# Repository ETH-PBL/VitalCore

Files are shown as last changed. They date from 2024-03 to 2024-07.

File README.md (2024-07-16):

# VitalCore
Philipp Schilk, ETHZ D-ITET PBL
2022-2024

A Self-contained, Miniaturized, BLE-enabled Embedded Platform for Low-Power, Wearable, and Hearable Applications.

<p float="center" align="center">
  
  
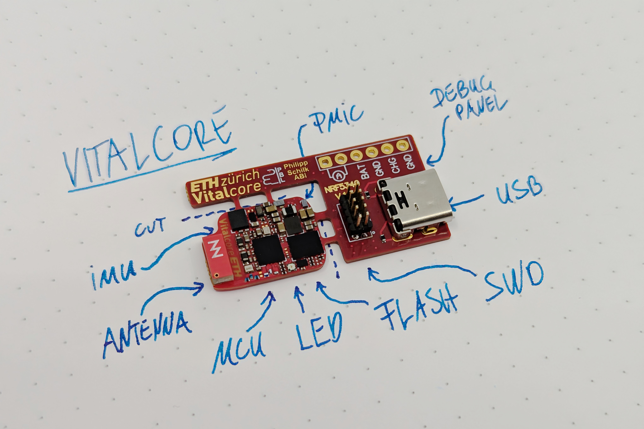
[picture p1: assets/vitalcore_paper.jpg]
  
  
</p>

Pictures: Frank K. Gürkaynak, 2022

## Quick Links

 - 📄 [Full Documentation](./hardware/VC_NRF5340/Documentation/Complete_1.3/VC_NRF5340_FULL_DOC.PDF)
 - 🌍 [Interactive HTML BOM](./hardware/VC_NRF5340/Documentation/Complete_1.3/VC_NRF5340-Complete.html)
 - 📦 [Gerbers](./hardware/VC_NRF5340/Documentation/Complete_1.3/Manufacturing)
 - 📦 [PnP Files](./hardware/VC_NRF5340/Documentation/Complete_1.3/PickAndPlace)
 - ⚙️  [Altium Project](./hardware/VC_NRF5340/)

## Changelog
 - 03/04/2024: First public release (Hardware v1.3)

## Overview

### VitalCore:

The VitalCore is a highly integrated, miniaturized embedded systems platform that features everything
a low-power wearable project usually requires - except for application specific sensors
and transducers. Its small 17.6 mm ** 12.6 mm size allows it to be integrated even in the most constraint
applications, include in-ear/hearable projects. Based around an NRF5340 SoC, the VitalCore features
a dual-core Cortex-M33 processor running at up to 128 MHz, 1 MB of Flash, 512 KB RAM, and BLE 5.2
complete with an on-board chip antenna.

### VitalPack Interface & Connectors:

On its back, the VitalCore features a 0.4 mm pitch 50-position connector that can be used to attach
application-specific 'VitalPack' expansion boards. This connector exposes power inputs and outputs,
the SoC's programming interface and USB port, and 28 GPIO pins with ADC, I2C, SPI, I2S, UART, QSPI, and PDM
interfaces available. The SWD pin, battery and charger connections, and QVAR inputs are also available as SMD solder
pads on the back side.

The exact pinout is specified in the [full documentation pdf](./hardware/VC_NRF5340/Documentation/Complete_1.3/VC_NRF5340_FULL_DOC.PDF).

To accommodate different stacking heights, the following combinations of header (on the VitalCore) and receptacles (on
the VitalPack) can be used:

| **Stacking Height** | **Header** | **Receptacle** |
| --- | --- | --- |
| 0.7mm | JAE Electronics WP7B-P050VA1-R8000 | JAE Electronics WP7B-S050VA1-R8000 |
| 1.5mm | Hirose DF40C-50DP-0.4V(51) | Hirose DF40C-50DS-0.4V(51) |
| 2.0mm | Hirose DF40C-2.0-50DP-0.4V(51) | Hirose DF40C-2.0-50DS-0.4V(51) |
| 2.5mm | Hirose DF40C-2.5-50DP-0.4V(51) | Hirose DF40C-2.5-50DS-0.4V(51) |

### Power:

A MAX77654 PMIC provides a full power subsystem, including a software-controlled battery charger with power path
switching and up to 300 mA charge current, a battery monitor, 3 software-controllable switch mode buck-boost converters each
with an output range of 0.8 V to 5.5 V, and two software-controlled LDOs each with an output range of 1.71 V to 5.3 V. All
on-board devices (SoC and peripherals) are powered using a dedicated 1.8 V buck converter, making all SMPS and LDO
outputs available application-specific circuitry via the VitalPack connector.

Power Diagram

### Peripherals:

The VitalCore comes equipped with the following peripherals:

 - A high-performance LSM6DSV16BX IMU with accelerometer, gyroscope and QVAR frontend.
 - A 256Mb W25Q256JWYIM QSPI Flash.
 - An RGB LED and IS31FL3194 driver capable of LED animations/patterns.

### Panel:

The VitalCore Altium project/gerber files include a panel to be used during development.
It exposes the NRF's SWD programming interface, USB port, power inputs, and power rail test points. It
can be removed manually by cutting the small PCB bridges, or be excluded before production entirely.

## Hardware

> [!IMPORTANT]
> Device sheet folder must be configured correctly in Altium for project to be opened correctly.

This project uses device sheets to for common building blocks (in `VC_Common`) that
are used in other projects. The folder `VC_Common/DevSheets` must be added to Altium's
list of device sheet locations! See below:

https://www.altium.com/documentation/altium-designer/device-sheets

To avoid annotation collision between components in device sheets and components within each project,
all device sheet components are annotated with a 'D' Suffix.  Altium should be able to handle this via
'Board Level Annotation', but it has been rather buggy.

Any modifications to device sheets don't seem to propagate to projects using those sheets until those
projects are closed & re-opened, or Altium is restarted.

## Firmware Template

**Will follow shortly**

## VitalPack Template

**Will follow shortly**

## Gallery & Examples

Examples of VitalCore-based projects:

### [TinyssimoRadar](https://github.com/ETH-PBL/TinyssimoRadar):
In-Ear Hand Gesture Recognition with Ultra-Low Power mmWave Radars.

<p align="center">
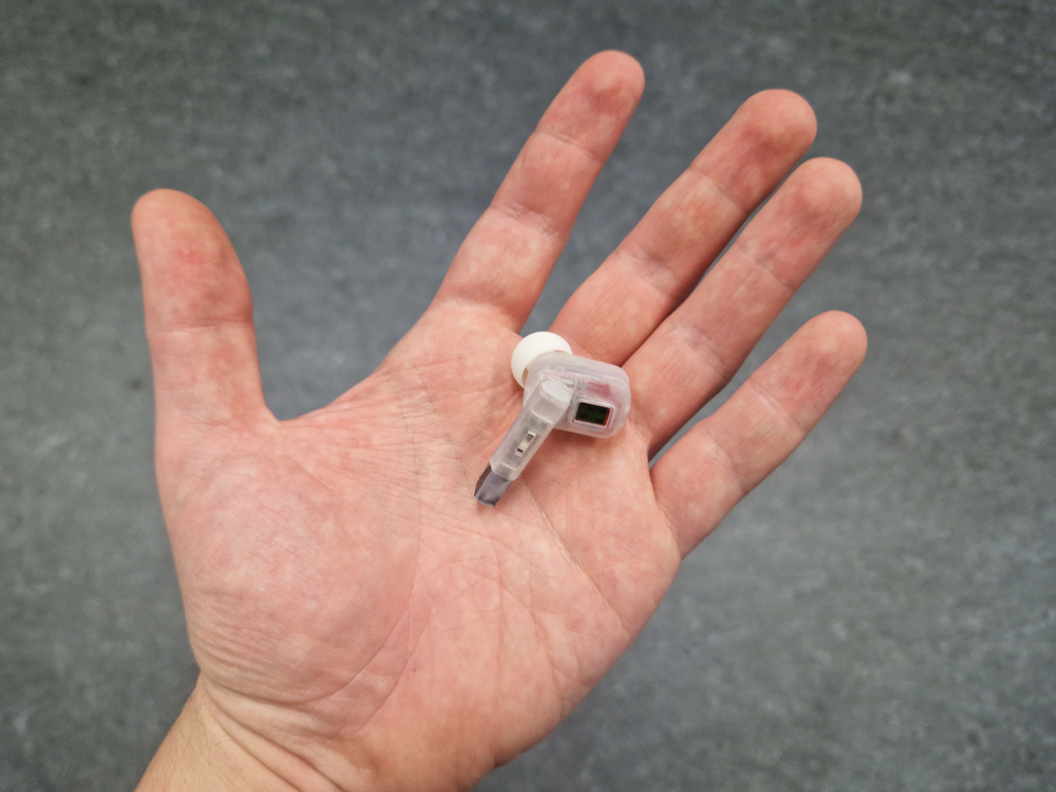
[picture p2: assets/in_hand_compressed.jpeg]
  
</p>

TinyssimoRadar Render

### VitalPod:
[*A Low Power In-Ear Vital Parameter Monitoring System*](https://ieeexplore.ieee.org/abstract/document/9941646)

### In-Ear-Voice:
[*Towards Milli-Watt Audio Enhancement With Bone-Conduction Microphones for In-Ear Sensing Platforms*](https://dl.acm.org/doi/abs/10.1145/3576842.3582365)

## License and Attribution

Published under the GNU GPLv3 license.

If you find VitalCore useful, we would appreciate if you cite one of the following papers:

📚 [Andrea Ronco, Philipp Schilk, Michele Magno, "TinyssimoRadar: In-Ear Hand Gesture Recognition with Ultra-Low Power mmWave Radars", *IoTDI'24*, 2024.](https://ieeexplore.ieee.org/abstract/document/10562162)
```bibtex
@inproceedings{TinyssimoRadar,
  author={Ronco, Andrea and Schilk, Philipp and Magno, Michele},
  booktitle={2024 IEEE/ACM Ninth International Conference on Internet-of-Things Design and Implementation (IoTDI)}, 
  title={TinyssimoRadar: In-Ear Hand Gesture Recognition with Ultra-Low Power mmWave Radars}, 
  year={2024},
  volume={},
  number={},
  pages={192-202},
  doi={10.1109/IoTDI61053.2024.00021}
}
```

📚 [Philipp Schilk, Niccolò Polvani, Andrea Ronco, Milos Cernak, Michele Magno, "In-Ear-Voice: Towards Milli-Watt Audio Enhancement With Bone-Conduction Microphones for In-Ear Sensing Platforms", *IoTDI'23*, 2023.](https://dl.acm.org/doi/abs/10.1145/3576842.3582365#)

```bibtex
@inproceedings{InEarVoice,
  author = {Schilk, Philipp and Polvani, Niccol\`{o} and Ronco, Andrea and Cernak, Milos and Magno, Michele},
  booktitle = {Proceedings of the 8th ACM/IEEE Conference on Internet of Things Design and Implementation},
  title = {In-Ear-Voice: Towards Milli-Watt Audio Enhancement With Bone-Conduction Microphones for In-Ear Sensing Platforms},
  year = {2023},
  isbn = {9798400700378},
  publisher = {Association for Computing Machinery},
  address = {New York, NY, USA},
  url = {https://doi.org/10.1145/3576842.3582365},
  doi = {10.1145/3576842.3582365},
  pages = {1–12},
  numpages = {12},
  series = {IoTDI '23}
}
```

📚 [Philipp Schilk, Kanika Dheman, Michele Magno,"VitalPod: A Low Power In-Ear Vital Parameter Monitoring System", *WiMob'22*, 2022.](https://ieeexplore.ieee.org/abstract/document/9941646)
```bibtex
@inproceedings{VitalPod,
  author={Schilk, Philipp and Dheman, Kanika and Magno, Michele},
  booktitle={2022 18th International Conference on Wireless and Mobile Computing, Networking and Communications (WiMob)}, 
  title={VitalPod: A Low Power In-Ear Vital Parameter Monitoring System}, 
  year={2022},
  volume={},
  number={},
  pages={94-99},
  doi={10.1109/WiMob55322.2022.9941646}
}
```

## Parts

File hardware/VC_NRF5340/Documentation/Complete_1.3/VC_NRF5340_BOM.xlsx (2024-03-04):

Designator | LibRef | Comment | Description | Quantity | Footprint | Manufacturer | Manufacturer Part Number | Supplier 1 | Supplier Part Number 1
C5D, C7, C8, C10, C11, C15 | CAP_0201_1u_10V | 1µF | CAP CER 1UF 10V X6S | 6 | CAP_0201 | Murata | GRM033C81A105ME05D | Mouser | 81-GRM033C81A105ME5D
C9 | CAP_0201_2.2n_16V | 2.2nF | CAP CER 2.2NF 16V X7R 0201 | 1 | CAP_0201 | Murata | GRM033R71C222KA88D | Mouser | 81-GRM033R71C222KA8D
C7D | CAP_0201_3.3n_16V | 3.3nF | CAP CER 3.3NF 16V X7R 0201 | 1 | CAP_0201 | Murata | GRM033R71C332KA88D | Mouser | 81-GRM033R71C332KA88
C1, C2, C2D, C3, C4, C5, C6, C14, C14D, C15D, C16D | CAP_0201_100n_10V | 100 nF | CAP CER 0.1UF 10V X5R 0201 | 11 | CAP_0201 | Murata | GRM033Z71A104KE14D | Mouser | 81-GRM033Z71A104KE4D
C17D, C18D | CAP_0201_110p_50V | 110pF | CAP CER 110PF 50V C0G 0201 | 2 | CAP_0201 | Murata | GRM0335C1H111JA01D | Mouser | 81-GRM0335C1H111JA1D
C3D, C4D, C12, C12D, C13, C13D | CAP_0402_4.7u_16V | 4.7µF | CAP CER 4.7UF 16V X5R 0402 | 6 | CAP_0402 | Kyocera AVX | 0402YD475MAT2A | Mouser | 581-0402YD475MAT2A
C6D | CAP_0402_10u_10V | 10µF | CAP CER 10UF 10V X5R 0402 | 1 | CAP_0402 | Samsung | CL05A106MP5NUNC | Mouser | 187-CL05A106MP5NUNC
C1D | CAP_0402_22u_6V3 | 22µF | CAP CER 22UF 6.3V X5R 0402 | 1 | CAP_0402 | Kyocera AVX | CM05X5R226M06AH080 | Mouser | 346-CM05X5R226M6AH80
C8D, C9D, C10D, C11D | CAP_0603_22u_10V | 22µF | CAP CER 22UF 10V X7R 0603 | 4 | CAP_0603 | Murata | GRM187R61A226ME15D | Mouser | 81-GRM187R61A226ME5D
C16 | CAP_RF_0201_0.7pF | 0.7pF | CAP RF CER 0.7PF 25V C0G 0201 | 1 | CAP_0201 | Murata | GJM0335C1ER70BB01D | Mouser | 81-GJM0335C1ER70BB1D
J2D | CONN_50P_M_COMBI_INTERFACE | Interface | 50Pin 0.4mm pitch connector footprint that accepts (male) connectors intended for different stacking heights: Hirose - DF40C-50DP-0.4V(51) for 1.5mm - 3mm stacking height JAE - WP7B-P050VA1-R8000 - for 0.7mm stacking height | 1 | CONN_COMBI_50P
J5D | CONN_PINHEADER_6PIN | 6Pin | 6 Pin Pinheader. | 1 | CONN_PINHEADER_6PIN
J4D | CONN_SWD | ARM SWD 10-pin | ARM 10-pin SWD Connector. | 1 | CONN_SWD |  |  | Mouser | 710-62201021121
J7D | CONN_USB_C | 213716-0001 USB-C | Connector USB Type C Receptacle 16 Position 0.5mm Surface Mount Right Angle Emboss T/R | 1 | CONN_USBC_2137160001 | Molex | 213716-0001 | Mouser | 538-213716-0001
D1D | D_NSR20F30NXT5G | NSR20F30NXT5G | Small Signal Schottky Diode, 30 V, 2 A | 1 | DSN2_ONSemi | ON Semiconductor | NSR20F30NXT5G | Mouser | 863-NSR20F30NXT5G
D2D | D_RGB_LED | SML-LX0404SIUPGUSB | SML-LX0404SIUPGUSB RGB LED | 1 | SML-LX0404SIUPGUSB | Lumex | SML-LX0404SIUPGUSB | Mouser | 696-LX0404SIUPGUSB
U7D | IS31FL3194 | IS31FL3194 | LED Driver with Programmable Pattern Sequencing 3-Channel 40mA 8-Pin WCSP T/R | 1 | WLCSP_8_P0.4 | ISSI | IS31FL3194-CLS2-TR | Digi-Key | 2521-IS31FL3194-CLS2-TRCT-ND
JP1D | JMP_0201 | 0R | ERJ Series 0201 0 Ohm 0.05 W Jumper Surface Mount Thick Film Chip Resistor | 1 | JMP_0201 | Panasonic | ERJ-1GN0R00C | Mouser | 667-ERJ-1GN0R00C
J1, J2, J3, J4, J5 | JMP_0201_3WAY | Solder Jumper | Solder Jumper 3 Pads | 5 | JMP_0201_3WAY | Panasonic | ERJ-1GN0R00C | Mouser | 667-ERJ-1GN0R00C
L1D | L_0603_2.2uH_520mA | 2.2µH | L 2.2uH 520mA 0603 | 1 | IND_0603 | Taiyo Yuden | MBKK1608T2R2M | Mouser | 963-MBKK1608T2R2M
L1, L2 | L_0603_10uH_300mA | 10µH | L 10uH 300mA 0603 | 2 | IND_0603 | Murata | LQM18DN100M70L | Mouser | 81-LQM18DN100M70L
L2D | L_0805_1.5uH_2A | 1.5µH | L 1.5uH 2A 0805 | 1 | IND_0805_DFE201210S | Murata | DFE201210S-1R5M=P2 | Mouser | 81-DFE201210S-1R5MP2
L4, L5 | L_RF_0201_2.2nH | 2.2nH | L 2.2nH RF 0201 | 2 | IND_0201_MURATA_LQW03AW | Murata | LQP03HQ2N2B02D | Mouser | 81-LQP03HQ2N2B02D
L3, L6, L7 | L_RF_0201_5.6nH | 5.6nH | L 5.6nH RF 0201 | 3 | IND_0201_MURATA_LQW03AW | Murata | LQW03AW5N6J00D | Mouser | 81-LQW03AW5N6J00D
U6D | LSM6DSV16BX | LSM6DSV16BX | IMU ACCEL/GYRO I2C/SPI 14LGA | 1 | LGA-14_STM | STMicroelectronics | LSM6DSV16BX | Mouser | 511-LSM6DSV16BXTR
U1D | MAX38640BENT18+T | MAX38640BENT18+T | Buck Switching Regulator IC Positive Fixed 1.8V 1 Output 175mA 6-WLP | 1 | THIN_WLP_6_MAX38640 | Maxim | MAX38640BENT18+T | Mouser | 700-MAX38640BENT18T
U2D | MAX77654BENV+T | MAX77654BENV+T | Buck-Boost Converter With LDO Regulator 5-OUT 30-Pin WLP T/R | 1 | WLP_30_MAX77654 | Maxim | MAX77654BENV+T | Mouser | 700-MAX77654BENV+T
E1 | NN03-320 | NN03-320 | Integrated Chip Antenna | 1 | NN03-320 | Fractus Antennas | NN03-320 | Mouser | 128-NN03-320
U1 | nRF5340-CLAA | nRF5340-CLAA | Multi-protocol Bluetooth Low Energy, IEEE 802.15.4, ANT and 2.4GHz proprietary system-on-chip | 1 | NRF5340_WLCSP | Nordic | NRF5340-CLAA-R7 | Mouser | 949-NRF5340-CLAA-R7
RT1D | NTC_0201_10k | 10kR | NTC 10K 1% 0201 3380K | 1 | RES_0201 | Panasonic | ERTJZEG103FA | Mouser | 667-ERT-JZEG103FA
U4D | PESD1USB30 | PESD1USB30 | ESD Suppressor Diode TVS Uni-Dir 5V 5-Pin WLCSP T/R | 1 | WLCSP_5_2-1-2_P0.4 | NXP Semiconductors | PESD1USB30 | Mouser | 771-PESD1USB30Z
R1, R2 | R_0201_2.2K | 2.2kR | R 2.2K 1% 50mW 0201 | 2 | RES_0201 | Panasonic | ERJ-1GNF2201C | Mouser | 667-ERJ-1GNF2201C
R3 | R_0201_2.2R | 2.2R | R 2.2R 1% 50mW 0201 | 1 | RES_0201 | Yageo | RC0201FR-072R2L | Mouser | 603-RC0201FR-072R2L
R4, R6D | R_0201_10K | 10kR | R 10K 1% 50mW 0201 | 2 | RES_0201 | Panasonic | ERJ-1GNF1002C | Mouser | 667-ERJ-1GNF1002C
R2D, R3D | R_0201_100K | 100kR | R 100K 1% 50mW 0201 | 2 | RES_0201 | Panasonic | ERJ-1GNF1003C | Mouser | 667-ERJ-1GNF1003C
R4D, R5D | R_0402_5K1 | 5K1 | R 5120R 1% 100mW 0402 | 2 | RES_0402 | Panasonic | ERJ-2RKF5101X | Mouser | 667-ERJ-2RKF5101X
U5D | W25Q256JWYIM | W25Q256JWYIM | NOR-Flash spiFlash, 1.8V, 256M-bit, 4Kb Uniform Sector, DTR | 1 | WLCSP_32_W25Q256JWYIM | Winbond | W25Q256JWYIM TR | Mouser | 454-W25Q256JWYIMTR
Y2 | Y_ECS-320-7-48B-JTM-TR5 | ECS-320-7-48B-JTM-TR5 (32MHz) | Crystal 32MHz 7pF ±20ppm ±20ppm 4-Pin Ultraminiature CSMD T/R | 1 | Y_ECX-1048 | ECS International | ECS-320-7-48B-JTM-TR5 | Mouser | 520-ECS320748BJTMTR5
Y1 | Y_ECS-327-9-1210 | ECS-.327-9-1210 (32.768kHz) | Crystal 32.768KHZ 9PFSMD ECX-1210 Khz Crystal 32.768KHZ 20PPM 90K Ohm -40C ~ 85C 2-SMD | 1 | Y_ECX-1210 | ECS International | ECS-.327-9-1210-TR | Mouser | 520-.327-9-1210T

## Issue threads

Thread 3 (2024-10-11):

Hardware: incorrect connection of W25Q256JW CS line

villanif, 2024-10-11:
W25Q256JW user manual specifies that "The /CS input must track the VCC supply level at power-up and power-down" (Page 10, section 4.1).

This issue can be solved by adding a pull-up resistor to the CS line

It is not sufficient to set the CS pin of the NRF53 pin to pull-up, as all pins are high-impedance during powerup

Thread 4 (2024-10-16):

Network Core Power Draw

schilkp, 2024-10-16:
Unexpected high DC power draw.

Tested with a VC with only the NRF53 soldered and powered directly via 1.8V.
With the network core enabled with BLE image and app core in sleep, power draw is around 5mA @ 1.8V
With the network core disabled and app core in sleep, power draw is less than 50uA @ 1.8V

Code to disable network core:
```c
NRF_RESET->NETWORK.FORCEOFF = RESET_NETWORK_FORCEOFF_FORCEOFF_Hold;
```

Seems like a hardware issue related to the network core? possibly oscillator or GPIO related?

villanif, 2024-10-16:
I briefly investigated if the issue could possibly be oscillator-related. In my opinion even with wrong oscillator parameters a 5mA draw cannot be explained, as a wrong oscillator setup should draw at most in the order of hundreds of uA (current can only be drawn by loading and unloading the capacitor). I guess the more likely explanation is a wrong GPIO configuration. According to the datasheet, GPIO electrical specifications, the current draw for the standard drive of the GPIO pin, the output set high, is at least 3 mA. If one grounded pin is pulled high by NRF, this would explain the data consumption.

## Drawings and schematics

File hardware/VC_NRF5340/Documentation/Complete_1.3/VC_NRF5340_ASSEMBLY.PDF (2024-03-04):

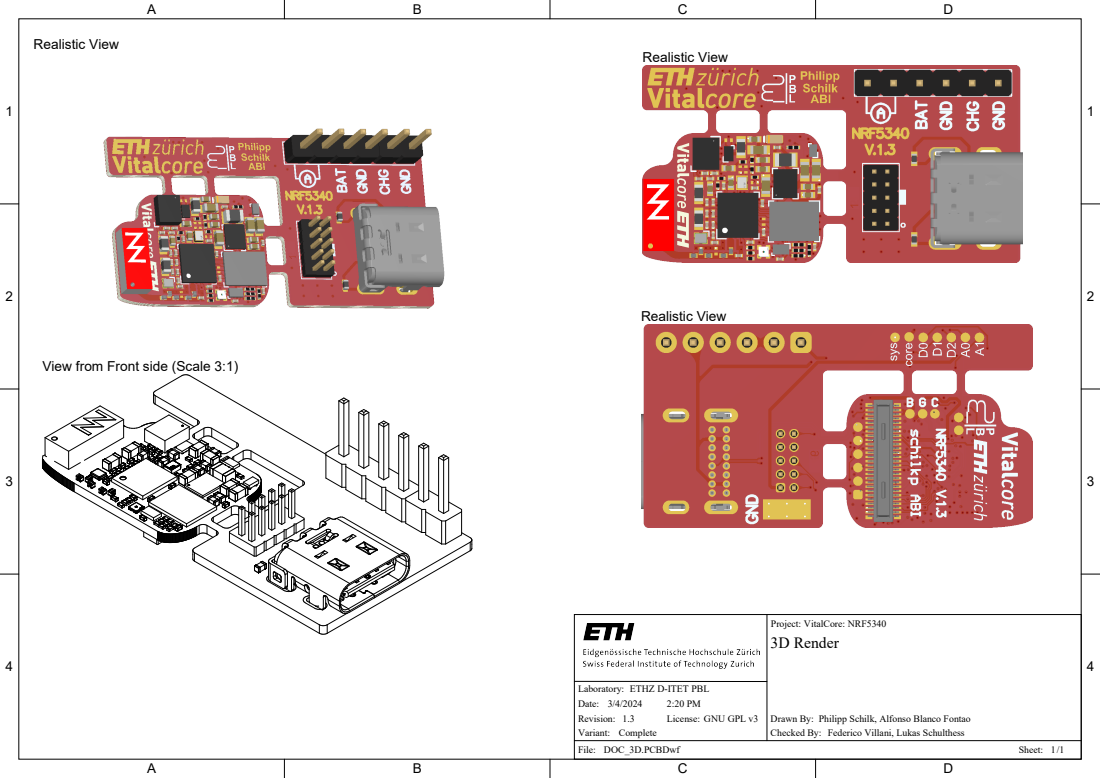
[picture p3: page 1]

View from Front side (Scale 3:1)

Drawn By: Philipp Schilk, Alfonso Blanco Fontao
Checked By:

Federico Villani, Lukas Schulthess

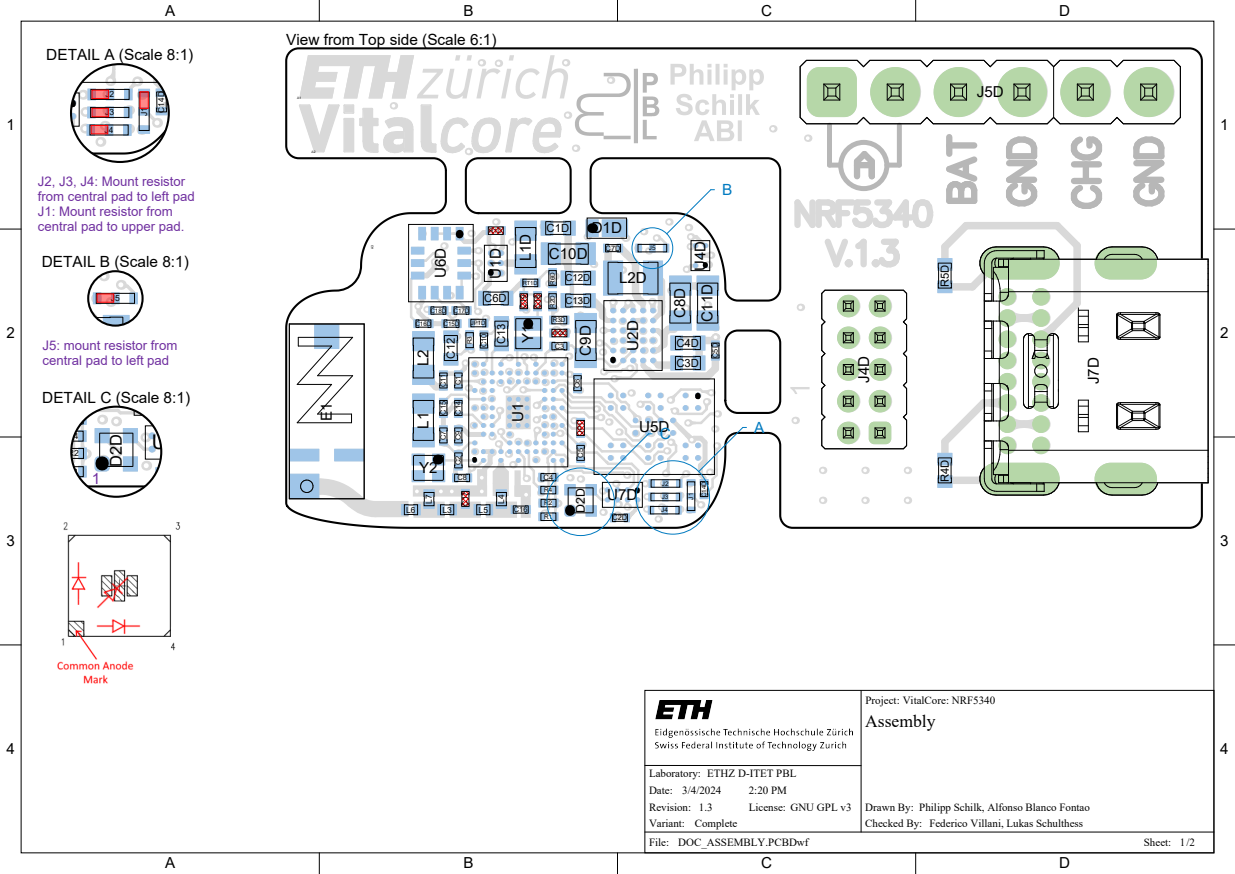
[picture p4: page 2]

View from Top side (Scale 6:1)

J2, J3, J4: Mount resistor
from central pad to left pad
J1: Mount resistor from
central pad to upper pad.

J5: mount resistor from
central pad to left pad
DETAIL C (Scale 8:1)

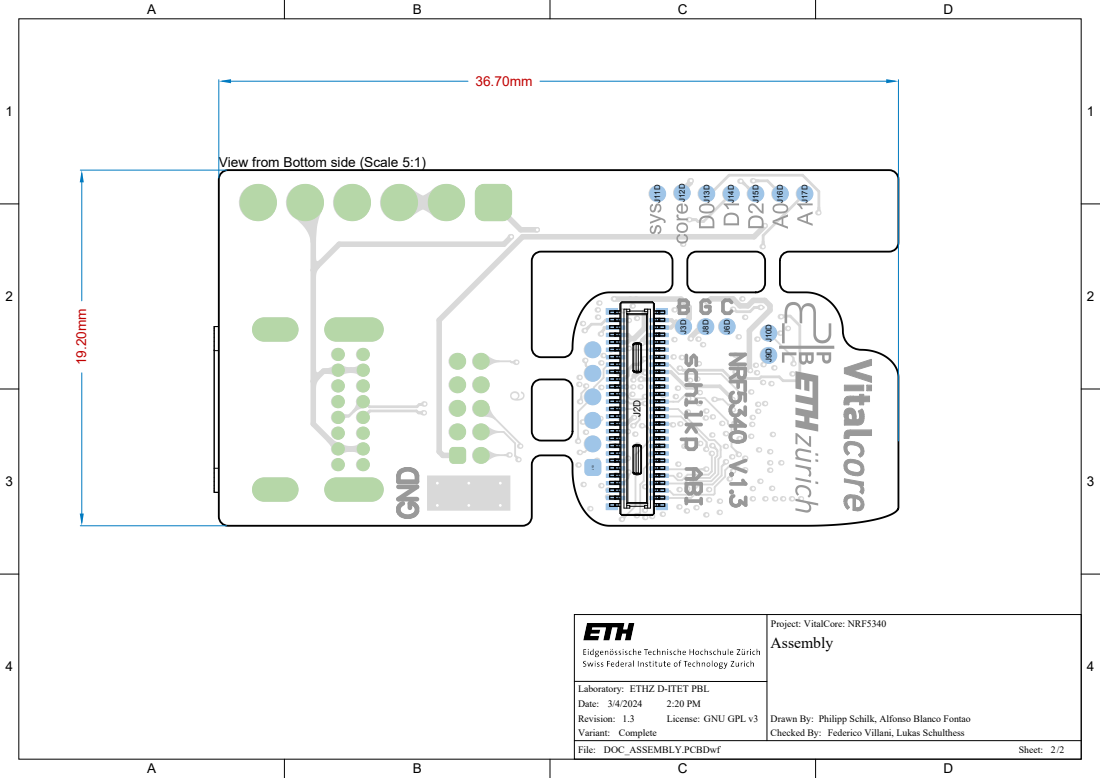
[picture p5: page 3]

View from Bottom side (Scale 5:1)

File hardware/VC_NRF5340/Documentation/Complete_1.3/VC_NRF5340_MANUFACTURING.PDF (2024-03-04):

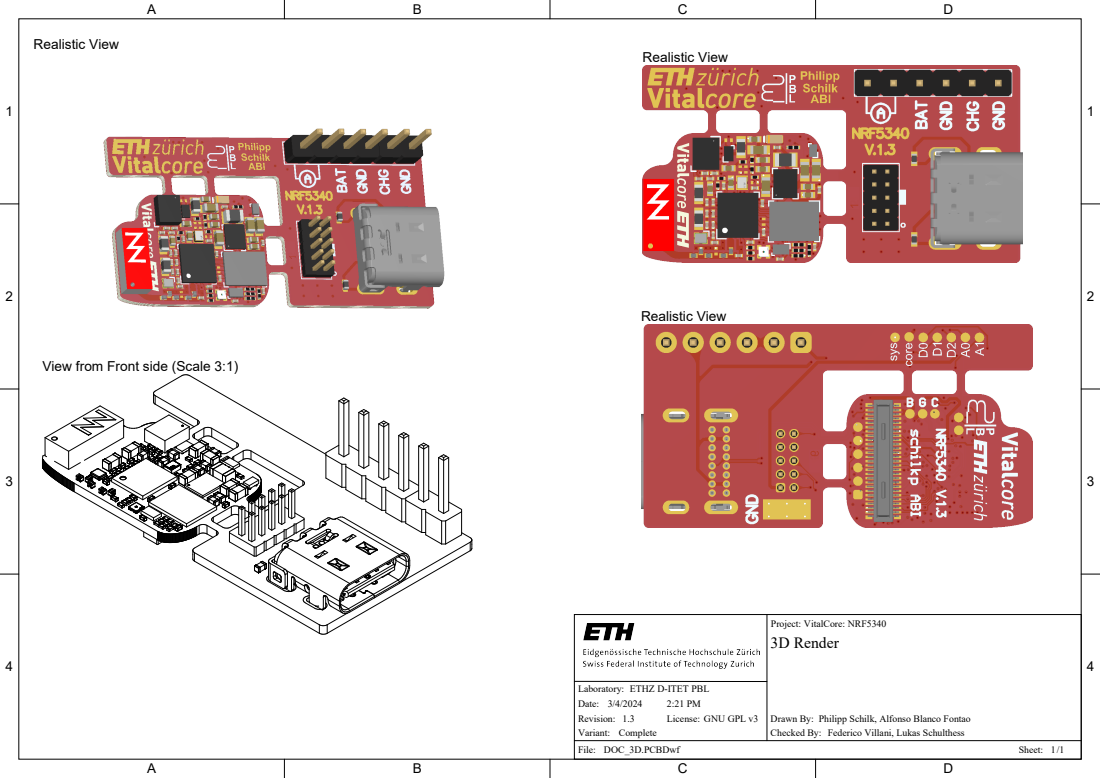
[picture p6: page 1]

View from Front side (Scale 3:1)

Drawn By: Philipp Schilk, Alfonso Blanco Fontao
Checked By:

Federico Villani, Lukas Schulthess

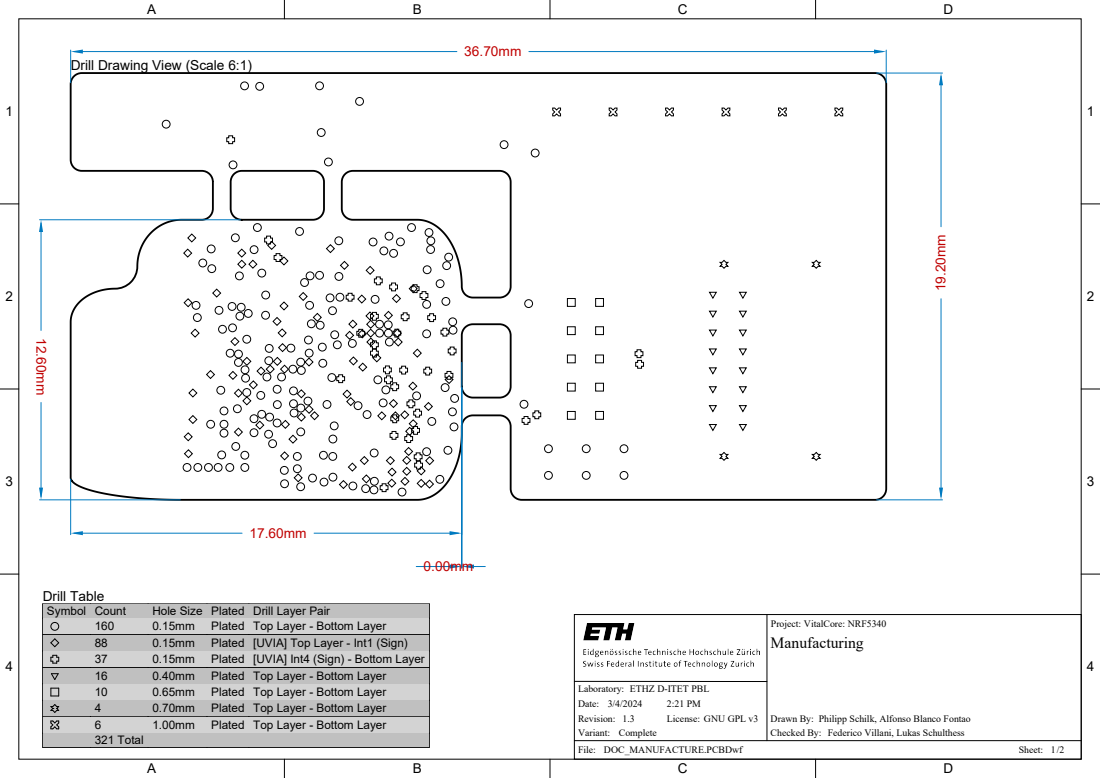
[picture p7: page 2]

Drill Drawing View (Scale 6:1)

Symbol | Count | Hole Size | Plated | Drill Layer Pair

160 | 0.15mm | Plated | Top Layer - Bottom Layer
88 | 0.15mm | Plated | [UVIA] Top Layer - Int1 (Sign)
37 | 0.15mm | Plated | [UVIA] Int4 (Sign) - Bottom Layer
16 | 0.40mm | Plated | Top Layer - Bottom Layer
10 | 0.65mm | Plated | Top Layer - Bottom Layer
4 | 0.70mm | Plated | Top Layer - Bottom Layer
6 | 1.00mm | Plated | Top Layer - Bottom Layer
321 Total

Project: VitalCore: NRF5340 Manufacturing

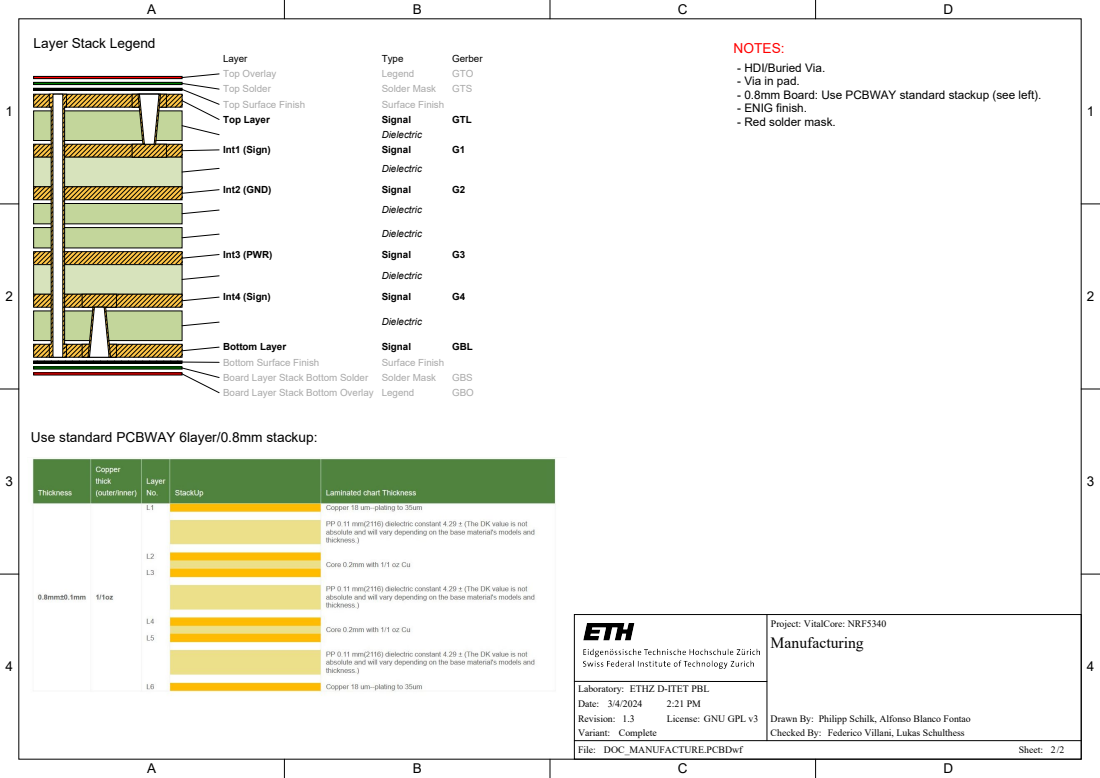
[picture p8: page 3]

NOTES:
- HDI/Buried Via.
- Via in pad.
- 0.8mm Board: Use PCBWAY standard stackup (see left).
- ENIG finish.
- Red solder mask.

Use standard PCBWAY 6layer/0.8mm stackup:

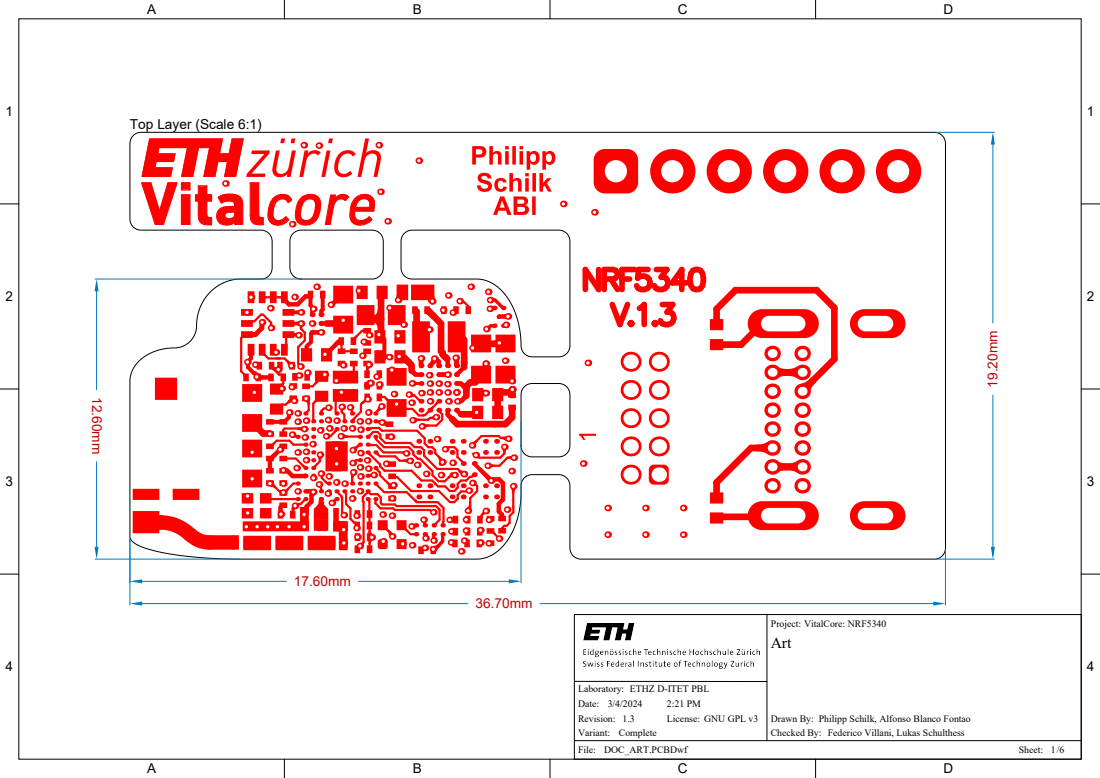
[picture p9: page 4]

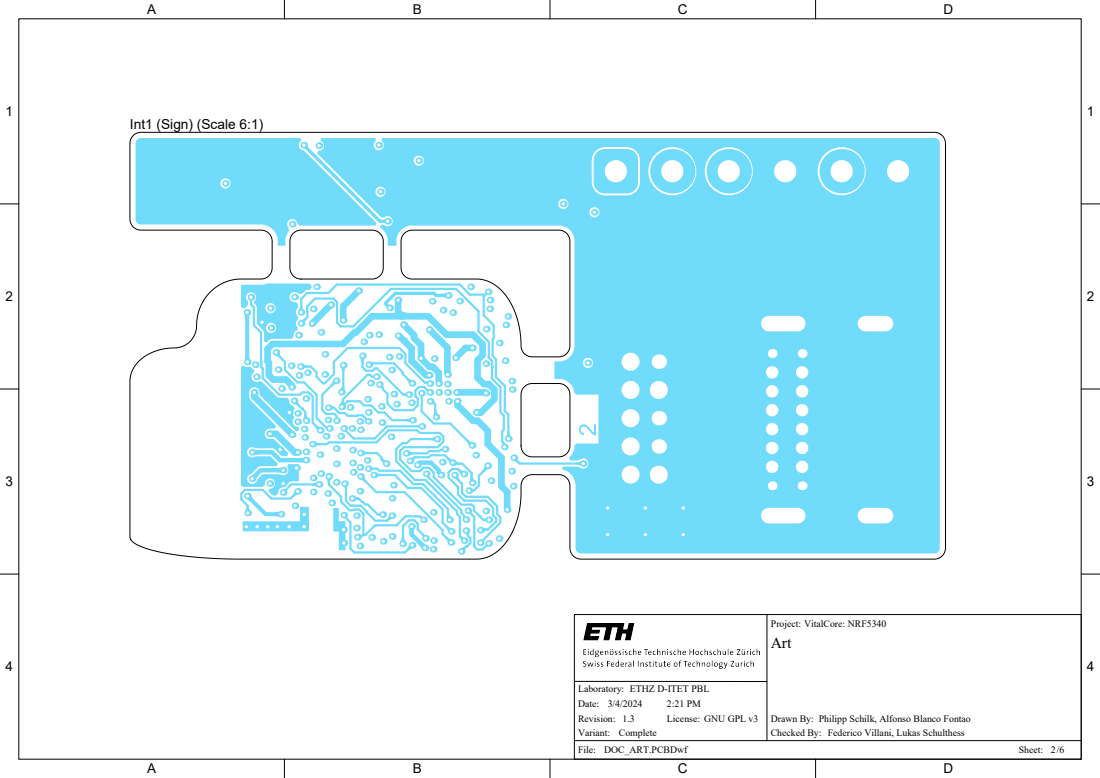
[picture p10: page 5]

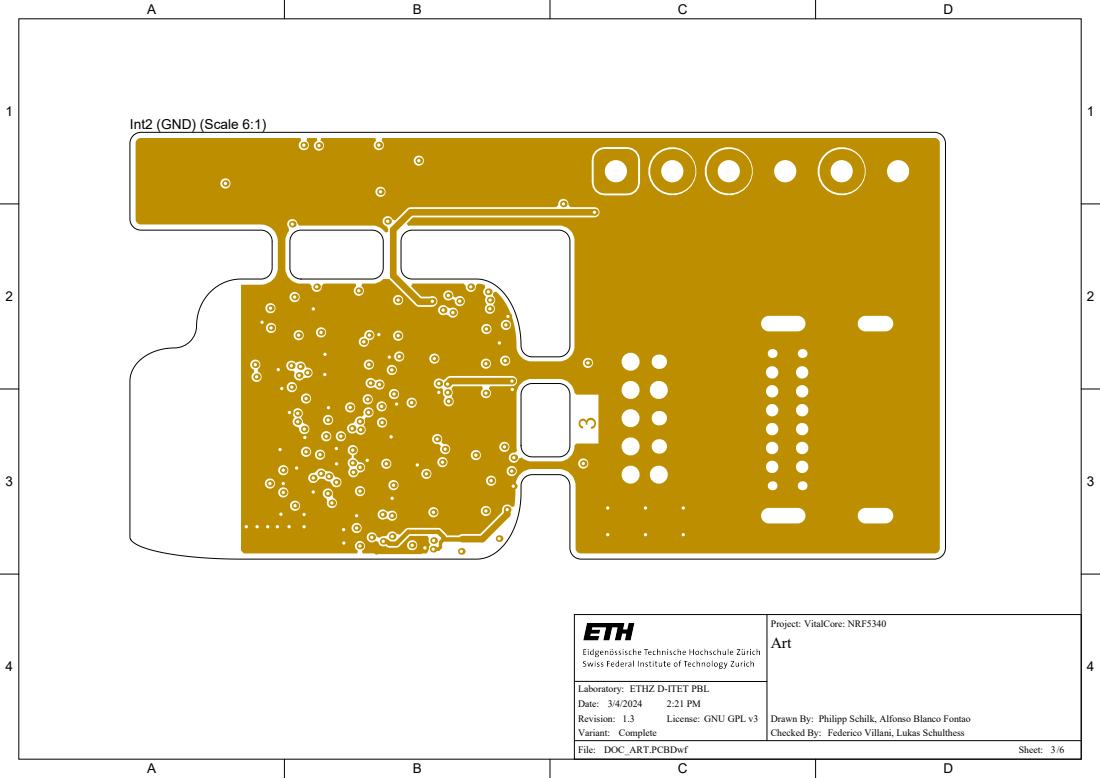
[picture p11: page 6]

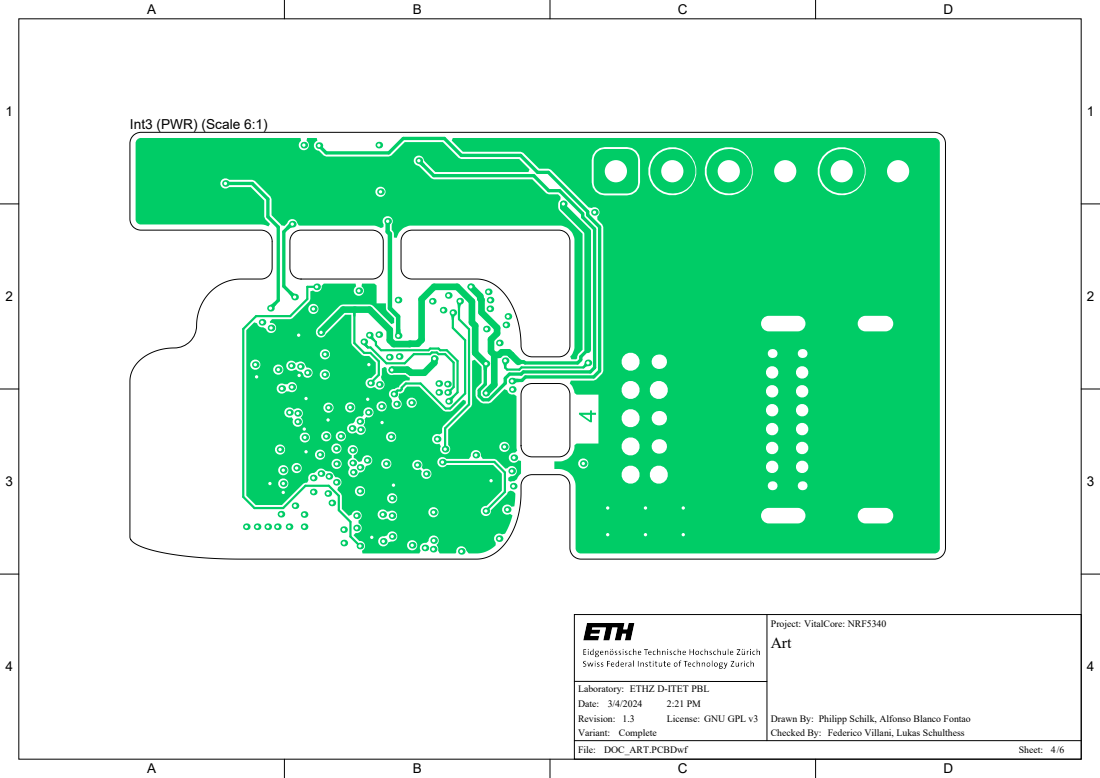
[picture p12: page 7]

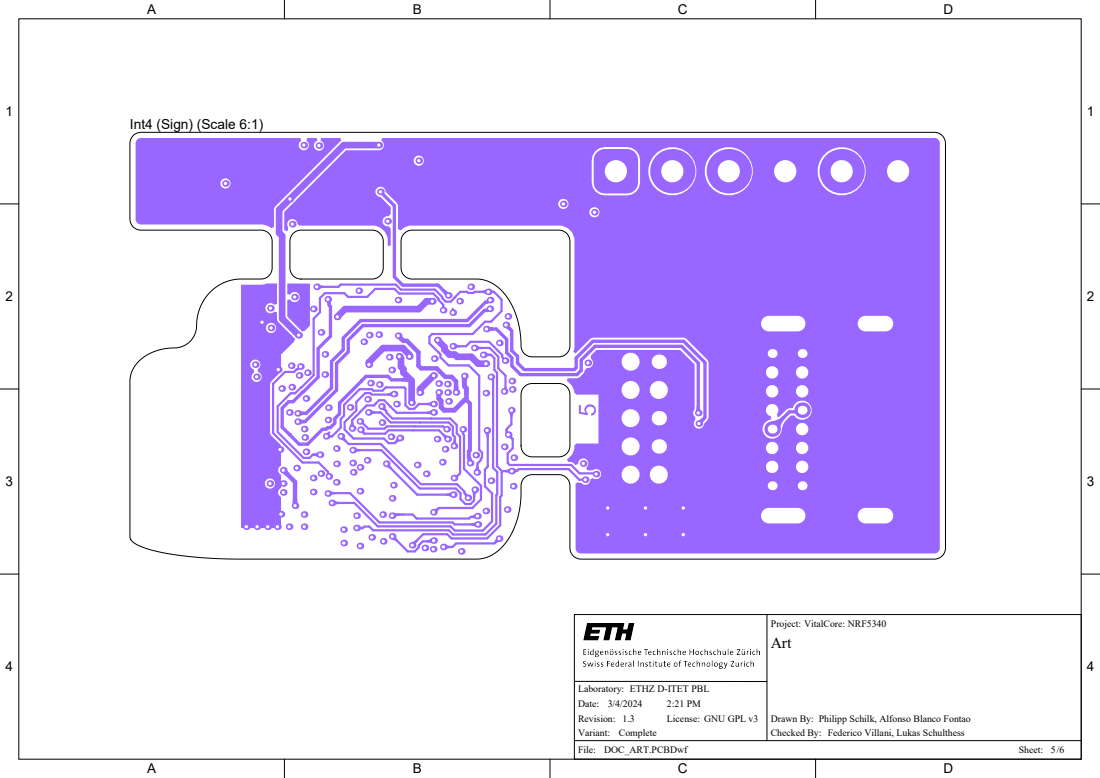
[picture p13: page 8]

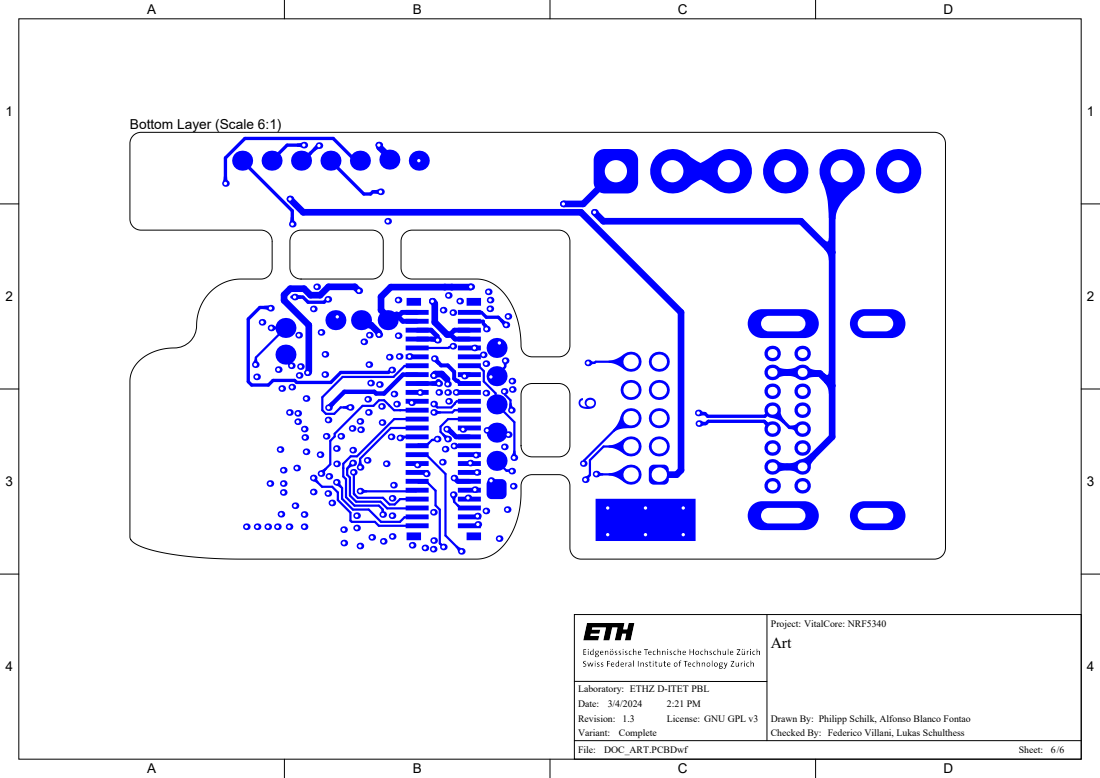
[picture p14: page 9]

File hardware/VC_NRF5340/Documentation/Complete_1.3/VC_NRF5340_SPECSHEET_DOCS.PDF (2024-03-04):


View from Front side (Scale 3:1)

Drawn By: Philipp Schilk, Alfonso Blanco Fontao
Checked By:

Federico Villani, Lukas Schulthess


View from Top side (Scale 6:1)

J2, J3, J4: Mount resistor
from central pad to left pad
J1: Mount resistor from
central pad to upper pad.

J5: mount resistor from
central pad to left pad
DETAIL C (Scale 8:1)


View from Bottom side (Scale 5:1)


View from Bottom side (Scale 2:1)


View from Top side (Scale 3:1)

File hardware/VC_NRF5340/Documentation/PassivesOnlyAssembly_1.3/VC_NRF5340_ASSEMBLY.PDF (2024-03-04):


View from Front side (Scale 3:1)

Drawn By: Philipp Schilk, Alfonso Blanco Fontao
Checked By:

Federico Villani, Lukas Schulthess


View from Top side (Scale 6:1)

J2, J3, J4: Mount resistor
from central pad to left pad
J1: Mount resistor from
central pad to upper pad.

J5: mount resistor from
central pad to left pad
DETAIL C (Scale 8:1)


View from Bottom side (Scale 5:1)

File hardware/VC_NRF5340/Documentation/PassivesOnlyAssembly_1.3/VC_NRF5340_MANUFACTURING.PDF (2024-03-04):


View from Front side (Scale 3:1)

Drawn By: Philipp Schilk, Alfonso Blanco Fontao
Checked By:

Federico Villani, Lukas Schulthess


Drill Drawing View (Scale 6:1)

Symbol | Count | Hole Size | Plated | Drill Layer Pair

160 | 0.15mm | Plated | Top Layer - Bottom Layer
88 | 0.15mm | Plated | [UVIA] Top Layer - Int1 (Sign)
37 | 0.15mm | Plated | [UVIA] Int4 (Sign) - Bottom Layer
16 | 0.40mm | Plated | Top Layer - Bottom Layer
10 | 0.65mm | Plated | Top Layer - Bottom Layer
4 | 0.70mm | Plated | Top Layer - Bottom Layer
6 | 1.00mm | Plated | Top Layer - Bottom Layer
321 Total

Project: VitalCore: NRF5340 Manufacturing


NOTES:
- HDI/Buried Via.
- Via in pad.
- 0.8mm Board: Use PCBWAY standard stackup (see left).
- ENIG finish.
- Red solder mask.

Use standard PCBWAY 6layer/0.8mm stackup:







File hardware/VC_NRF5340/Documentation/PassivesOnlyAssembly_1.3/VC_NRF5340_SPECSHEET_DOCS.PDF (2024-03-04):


View from Front side (Scale 3:1)

Drawn By: Philipp Schilk, Alfonso Blanco Fontao
Checked By:

Federico Villani, Lukas Schulthess


View from Top side (Scale 6:1)

J2, J3, J4: Mount resistor
from central pad to left pad
J1: Mount resistor from
central pad to upper pad.

J5: mount resistor from
central pad to left pad
DETAIL C (Scale 8:1)


View from Bottom side (Scale 5:1)


View from Bottom side (Scale 2:1)


View from Top side (Scale 3:1)

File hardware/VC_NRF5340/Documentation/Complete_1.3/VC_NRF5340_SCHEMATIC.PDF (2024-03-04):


VitalCore Logo VitalCore Vitalcore ETH Logo Vitalcore ETH


L 5
L 1 1


or may act as
nected



1 1


Drawn By:
Checked By: Federico Villani, Lukas Schulthess


Line # | Designator | Comment | Quantity | Design Item Id | Manufacturer | Manufacturer Part Number
1 | C1, C2, C2D, C3, C4, C5, C6, C14, C14D, C15D, C16D | 100 nF | 11 | CAP_0201_100n_10V | Murata | GRM033Z71A104KE14D

2 | C1D | 22µF | 1 | CAP_0402_22u_6V3 | Kyocera AVX | CM05X5R226M06AH080
3 | C3D, C4D, C12, C12D, C13, C13D | 4.7µF | 6 | CAP_0402_4.7u_16V | Kyocera AVX | 0402YD475MAT2A
4 | C5D, C7, C8, C10, C11, C15 | 1µF | 6 | CAP_0201_1u_10V | Murata | GRM033C81A105ME05D
5 | C6D | 10µF | 1 | CAP_0402_10u_10V | Samsung | CL05A106MP5NUNC
6 | C7D | 3.3nF | 1 | CAP_0201_3.3n_16V | Murata | GRM033R71C332KA88D
7 | C8D, C9D, C10D, C11D | 22µF | 4 | CAP_0603_22u_10V | Murata | GRM187R61A226ME15D
8 | C9 | 2.2nF | 1 | CAP_0201_2.2n_16V | Murata | GRM033R71C222KA88D
9 | C16 | 0.7pF | 1 | CAP_RF_0201_0.7pF | Murata | GJM0335C1ER70BB01D
10 | C17D, C18D | 110pF | 2 | CAP_0201_110p_50V | Murata | GRM0335C1H111JA01D
11 | D1D | NSR20F30NXT5G | 1 | D_NSR20F30NXT5G | ON Semiconductor | NSR20F30NXT5G
12 | D2D | SML-LX0404SIUPGUSB | 1 | D_RGB_LED | Lumex | SML-LX0404SIUPGUSB
13 | E1 | NN03-320 | 1 | NN03-320 | Fractus Antennas | NN03-320
14 | J1, J2, J3, J4, J5 | Solder Jumper | 5 | JMP_0201_3WAY | Panasonic | ERJ-1GN0R00C
15 | J2D | Interface | 1 | CONN_50P_M_COMBI_INT ERFACE

16 | J4D | ARM SWD 10-pin | 1 | CONN_SWD
17 | J5D | 6Pin | 1 | CONN_PINHEADER_6PIN
18 | J7D | 213716-0001 USB-C | 1 | CONN_USB_C | Molex | 213716-0001
19 | JP1D | 0R | 1 | JMP_0201 | Panasonic | ERJ-1GN0R00C
20 | L1, L2 | 10µH | 2 | L_0603_10uH_300mA | Murata | LQM18DN100M70L
21 | L1D | 2.2µH | 1 | L_0603_2.2uH_520mA | Taiyo Yuden | MBKK1608T2R2M
22 | L2D | 1.5µH | 1 | L_0805_1.5uH_2A | Murata | DFE201210S-1R5M=P2
23 | L3, L6, L7 | 5.6nH | 3 | L_RF_0201_5.6nH | Murata | LQW03AW5N6J00D
24 | L4, L5 | 2.2nH | 2 | L_RF_0201_2.2nH | Murata | LQP03HQ2N2B02D
25 | R1, R2 | 2.2kR | 2 | R_0201_2.2K | Panasonic | ERJ-1GNF2201C
26 | R2D, R3D | 100kR | 2 | R_0201_100K | Panasonic | ERJ-1GNF1003C
27 | R3 | 2.2R | 1 | R_0201_2.2R | Yageo | RC0201FR-072R2L
28 | R4, R6D | 10kR | 2 | R_0201_10K | Panasonic | ERJ-1GNF1002C
29 | R4D, R5D | 5K1 | 2 | R_0402_5K1 | Panasonic | ERJ-2RKF5101X
30 | RT1D | 10kR | 1 | NTC_0201_10k | Panasonic | ERTJZEG103FA
31 | U1 | nRF5340-CLAA | 1 | nRF5340-CLAA | Nordic | NRF5340-CLAA-R7
32 | U1D | MAX38640BENT18+T | 1 | MAX38640BENT18+T | Maxim | MAX38640BENT18+T
33 | U2D | MAX77654BENV+T | 1 | MAX77654BENV+T | Maxim | MAX77654BENV+T
34 | U4D | PESD1USB30 | 1 | PESD1USB30 | NXP Semiconductors | PESD1USB30
35 | U5D | W25Q256JWYIM | 1 | W25Q256JWYIM | Winbond | W25Q256JWYIM TR
36 | U6D | LSM6DSV16BX | 1 | LSM6DSV16BX | STMicroelectronics | LSM6DSV16BX
37 | U7D | IS31FL3194 | 1 | IS31FL3194 | ISSI | IS31FL3194-CLS2-TR
38 | Y1 | ECS-.327-9-1210 (32.768kHz) | 1 | Y_ECS-327-9-1210 | ECS International | ECS-.327-9-1210-TR
39 | Y2 | ECS-320-7-48B-JTM-TR5 (32MHz) | 1 | Y_ECS-320-7-48B-JTM-TR5 | ECS International | ECS-320-7-48B-JTM-TR5

Drawn By: Philipp Schilk, Alfonso Blanco Fontao
Checked By:

Federico Villani, Lukas Schulthess

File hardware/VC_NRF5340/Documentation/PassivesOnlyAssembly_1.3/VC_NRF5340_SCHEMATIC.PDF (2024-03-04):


VitalCore Logo VitalCore Vitalcore ETH Logo Vitalcore ETH


L 5
L 1 1


or may act as
nected



1 1


Drawn By:
Checked By: Federico Villani, Lukas Schulthess


Line # | Designator | Comment | Quantity | Design Item Id | Manufacturer | Manufacturer Part Number
1 | C1, C2, C2D, C3, C4, C5, C6, C14, C14D, C15D, C16D | 100 nF | 11 | CAP_0201_100n_10V | Murata | GRM033Z71A104KE14D

2 | C1D | 22µF | 1 | CAP_0402_22u_6V3 | Kyocera AVX | CM05X5R226M06AH080
3 | C3D, C4D, C12, C12D, C13, C13D | 4.7µF | 6 | CAP_0402_4.7u_16V | Kyocera AVX | 0402YD475MAT2A
4 | C5D, C7, C8, C10, C11, C15 | 1µF | 6 | CAP_0201_1u_10V | Murata | GRM033C81A105ME05D
5 | C6D | 10µF | 1 | CAP_0402_10u_10V | Samsung | CL05A106MP5NUNC
6 | C7D | 3.3nF | 1 | CAP_0201_3.3n_16V | Murata | GRM033R71C332KA88D
7 | C8D, C9D, C10D, C11D | 22µF | 4 | CAP_0603_22u_10V | Murata | GRM187R61A226ME15D
8 | C9 | 2.2nF | 1 | CAP_0201_2.2n_16V | Murata | GRM033R71C222KA88D
9 | C16 | 0.7pF | 1 | CAP_RF_0201_0.7pF | Murata | GJM0335C1ER70BB01D
10 | C17D, C18D | 110pF | 2 | CAP_0201_110p_50V | Murata | GRM0335C1H111JA01D
11 | D1D | NSR20F30NXT5G | 1 | D_NSR20F30NXT5G | ON Semiconductor | NSR20F30NXT5G
12 | D2D | SML-LX0404SIUPGUSB | 1 | D_RGB_LED | Lumex | SML-LX0404SIUPGUSB
13 | E1 | NN03-320 | 1 | NN03-320 | Fractus Antennas | NN03-320
14 | J1, J2, J3, J4, J5 | Solder Jumper | 5 | JMP_0201_3WAY | Panasonic | ERJ-1GN0R00C
15 | JP1D | 0R | 1 | JMP_0201 | Panasonic | ERJ-1GN0R00C
16 | L1, L2 | 10µH | 2 | L_0603_10uH_300mA | Murata | LQM18DN100M70L
17 | L1D | 2.2µH | 1 | L_0603_2.2uH_520mA | Taiyo Yuden | MBKK1608T2R2M
18 | L2D | 1.5µH | 1 | L_0805_1.5uH_2A | Murata | DFE201210S-1R5M=P2
19 | L3, L6, L7 | 5.6nH | 3 | L_RF_0201_5.6nH | Murata | LQW03AW5N6J00D
20 | L4, L5 | 2.2nH | 2 | L_RF_0201_2.2nH | Murata | LQP03HQ2N2B02D
21 | R1, R2 | 2.2kR | 2 | R_0201_2.2K | Panasonic | ERJ-1GNF2201C
22 | R2D, R3D | 100kR | 2 | R_0201_100K | Panasonic | ERJ-1GNF1003C
23 | R3 | 2.2R | 1 | R_0201_2.2R | Yageo | RC0201FR-072R2L
24 | R4, R6D | 10kR | 2 | R_0201_10K | Panasonic | ERJ-1GNF1002C
25 | R4D, R5D | 5K1 | 2 | R_0402_5K1 | Panasonic | ERJ-2RKF5101X
26 | RT1D | 10kR | 1 | NTC_0201_10k | Panasonic | ERTJZEG103FA
27 | U4D | PESD1USB30 | 1 | PESD1USB30 | NXP Semiconductors | PESD1USB30
28 | Y1 | ECS-.327-9-1210 (32.768kHz) | 1 | Y_ECS-327-9-1210 | ECS International | ECS-.327-9-1210-TR
29 | Y2 | ECS-320-7-48B-JTM-TR5 (32MHz) | 1 | Y_ECS-320-7-48B-JTM-TR5 | ECS International | ECS-320-7-48B-JTM-TR5

Drawn By: Philipp Schilk, Alfonso Blanco Fontao
Checked By:

Federico Villani, Lukas Schulthess
